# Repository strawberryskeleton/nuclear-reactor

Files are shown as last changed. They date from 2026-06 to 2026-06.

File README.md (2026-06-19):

# nuclear-reactor
ironman's arc reactor themed sound responsive pendant

## Inspiration from:
Link: [link to youtube video](https://www.youtube.com/watch?v=0NRY9WaExDg)

## Features
- has a ironman arc reactor top plate
- the case should be translucent enough for light to shine through
- has rechargeable battery
- programmable leds to react to sound picked up from mic
- has a notch to attach ribbon to make it a pendant

## Schematics
> microcontroller used is Xiao ESP32-S3 + charger module is not needed

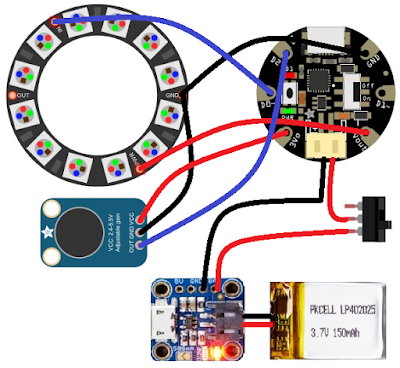
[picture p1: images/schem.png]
schem


## Case - 3D Printed

case assembled - top
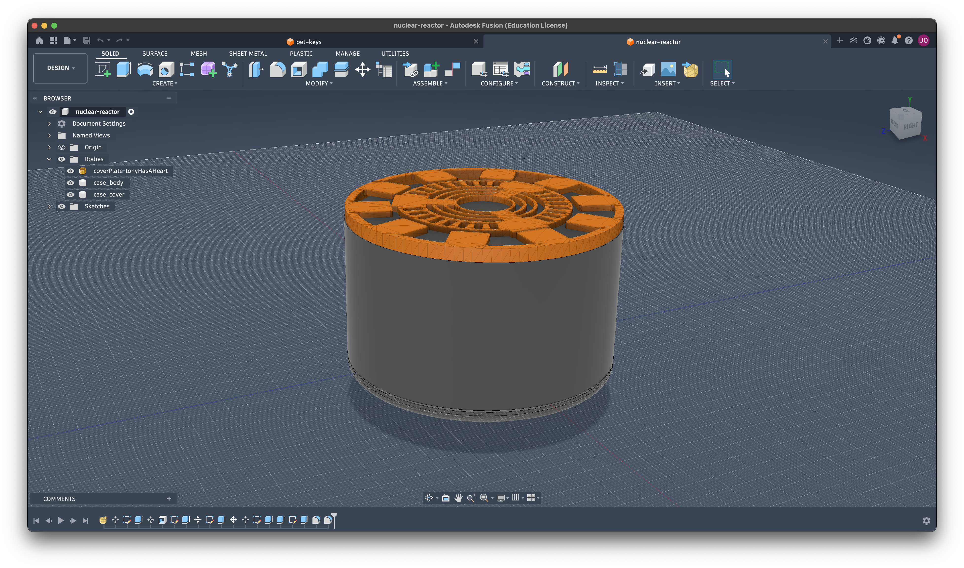
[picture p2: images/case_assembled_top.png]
case assembled - top


case assembled - bottom
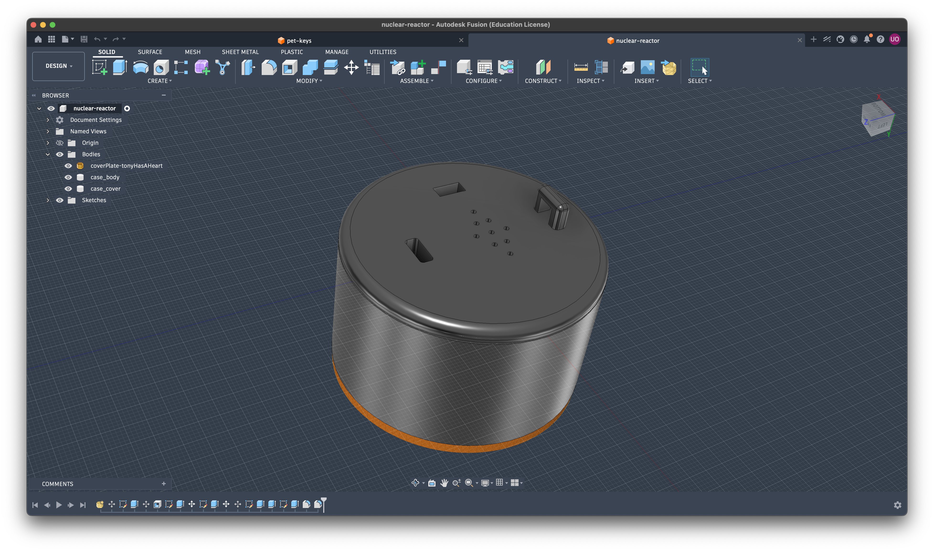
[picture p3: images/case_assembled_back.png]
case assembled - bottom


case lid
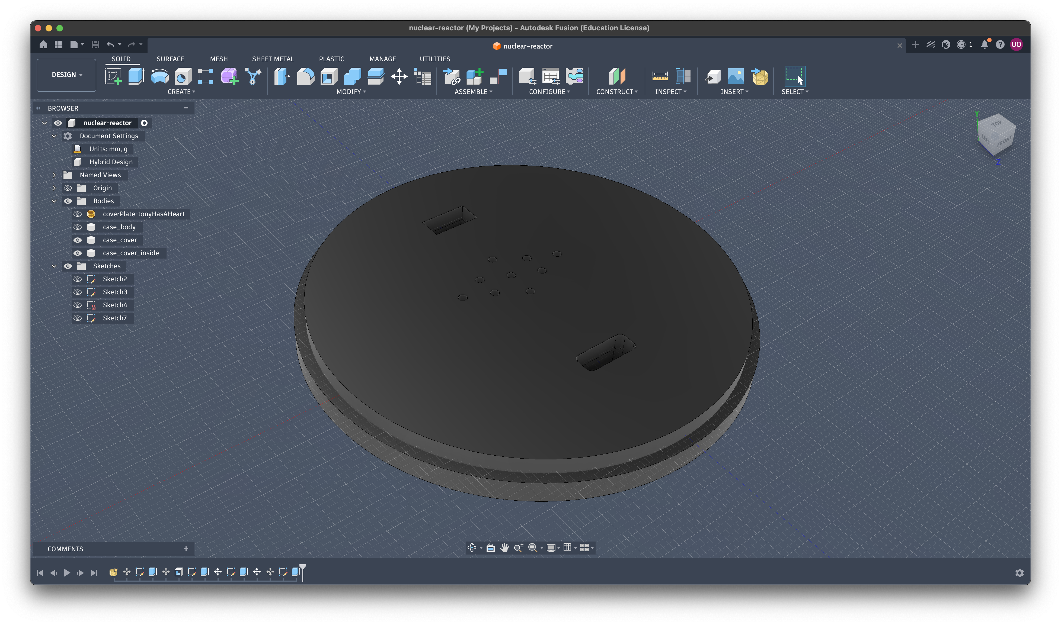
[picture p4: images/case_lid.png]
case lid


## BOM
| S. | Component | Quantity | Price (INR) | Price (USD) | Link |
|----|---|---|---|---|---|
| 1. | 3D Printed Case | 1 | (shipping only) | - | from printing-legion |
| 2. | Xiao ESP32-S3 | 1 | 1034.00 | 10.96 | https://robocraze.com/products/seeed-studio-xiao-esp32-s3-development-board-supports-wi-fi-bluetooth-5-0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 |
| 3. | Slide Switch SPDT | 1 | 9.00 | 0.095 | https://robocraze.com/products/slide-switch-3-pin-2-way-spdt?variant=44698610237664 |
| 4. | Rechargeable LiPo Battery | 1 | 102.00 | 1.08 | https://robocraze.com/products/witty-fox-160mah-rechargeable-3-7v-lipo-battery?variant=47479826481376 |
| 5. | WS2812 7-Bit Round LED Board | 1 | 89.00 | 0.94 | https://www.amazon.in/gp/product/B073DDRSLD/ref=ox_sc_act_title_1?smid=A31PUIOPHJ56Y3&psc=1 |
| 6. | MAX4466 Microphone Amplifier | 1 | 222.00 | 2.35 | https://www.amazon.in/gp/product/B0973CRZ25/ref=ox_sc_act_title_3?smid=A31PUIOPHJ56Y3&psc=1 |
| 7. | WS2812b LED Strip Lights | 1 | 249.00 | 2.64 | https://www.amazon.in/gp/product/B0CXVKBRM8/ref=ox_sc_act_title_2?smid=A5EYW98BF5M8Q&th=1 |

**Total Cost**: 1705.00 INR = 18.07 USD (excluding shipping needed by printing legion)

> Note #1: need something around $20-$22 to cover any conversion tax + shipping by printing legion

> Note #2: conversion rate might change. one in BOM is as per google on 19 Jun 1:25am IST

> NOTE #3: had to get 1m led strip since couldn't find any that was shorter

## Credits
- made by me
- 3D case made in Fusion
- Schem in KiCad
- case top design plate from: [https://www.printables.com/model/624553-wearable-arc-reactor/files]

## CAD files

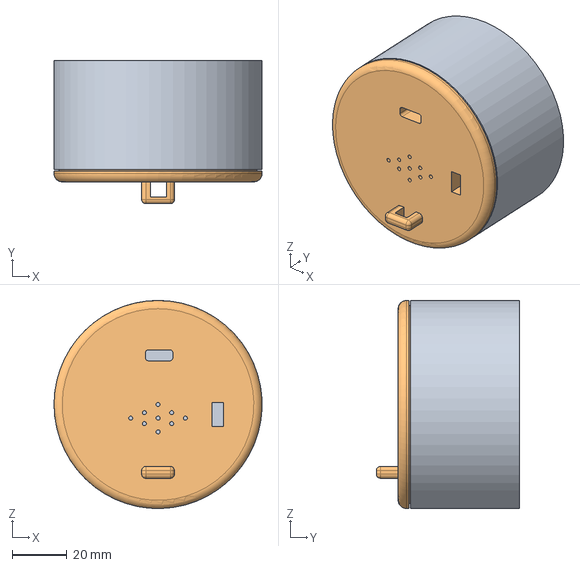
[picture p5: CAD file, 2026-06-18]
files/case_assembled.step
76.1 x 52.5 x 76.1 mm

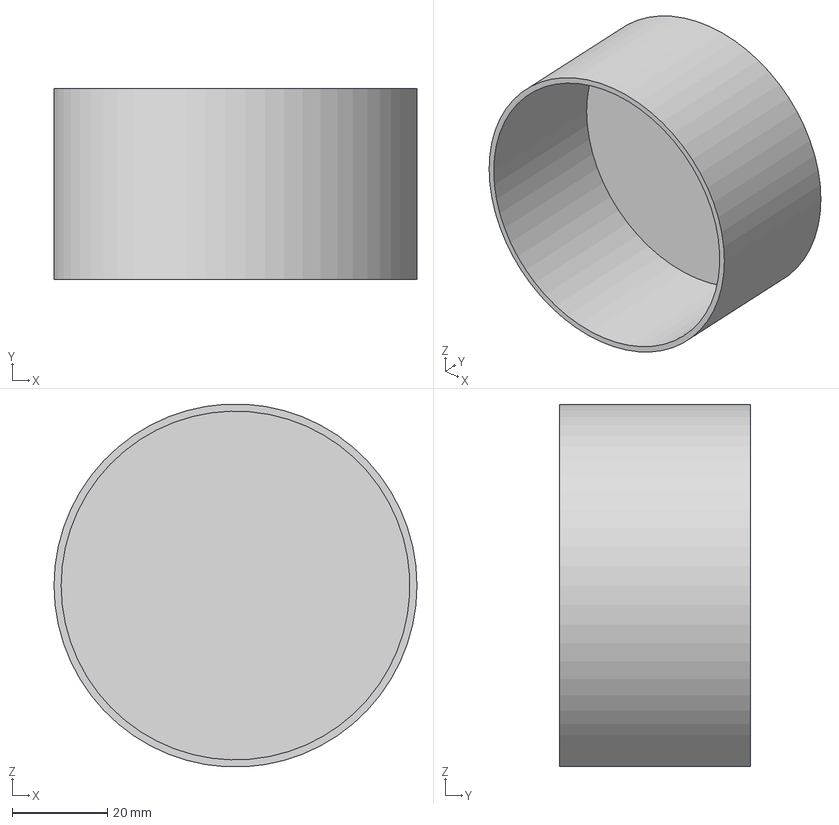
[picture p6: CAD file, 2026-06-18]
files/case_body.step
76.2 x 40.0 x 76.0 mm

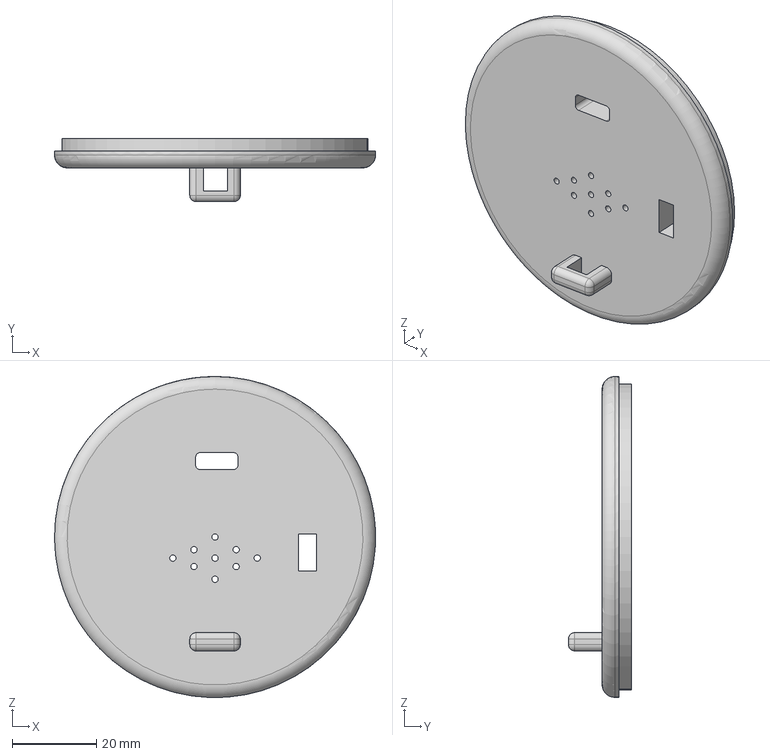
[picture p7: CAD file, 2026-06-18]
files/case_lid.step
76.1 x 15.0 x 76.1 mm

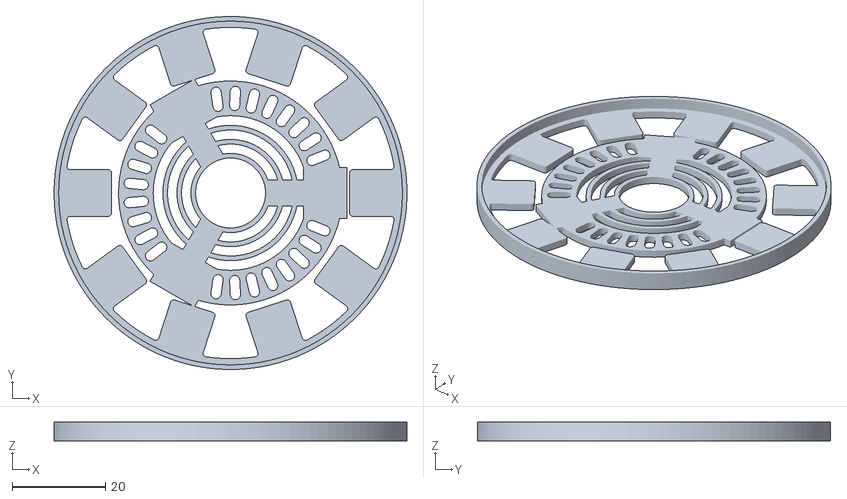
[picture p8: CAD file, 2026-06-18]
files/coverPlate-tonyHasAHeart.stl
75.6 x 75.6 x 4.00

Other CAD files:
files/base_lid.stl
files/case_assembled.stl
files/case_body.stl

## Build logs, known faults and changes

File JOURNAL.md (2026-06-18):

# JOURNAL
---
**Date: 18 Jun, 1:00am**

**Time Spent: 1hr 15min**

**What I Did:**

1. researched about the project like electronics needed, case, what other people have already made, etc.

2. made a few rough designs

rough design page #1
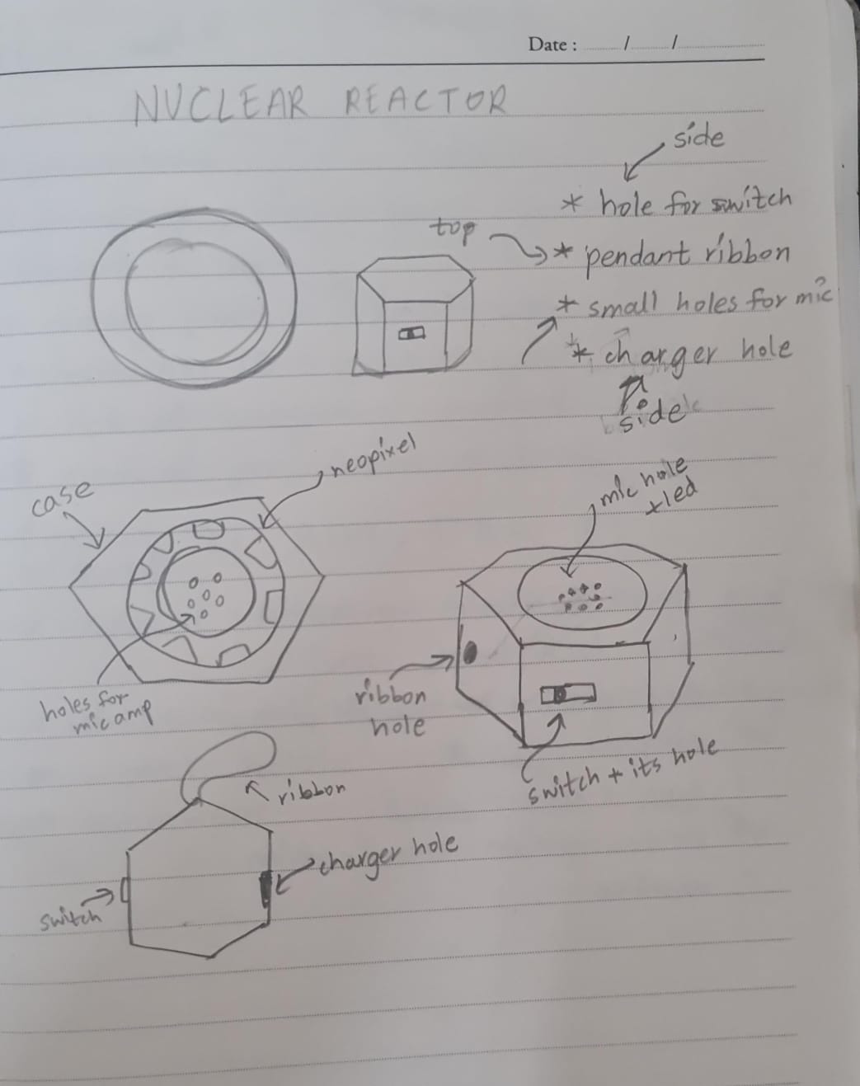
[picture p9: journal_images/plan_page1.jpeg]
rough design page #1


rough design page #2
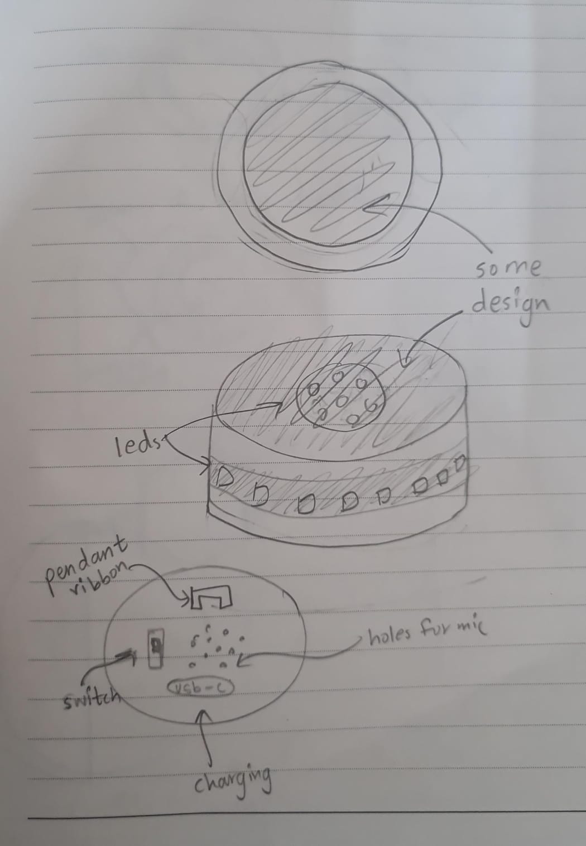
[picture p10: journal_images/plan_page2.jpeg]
rough design page #1


3. went to sleep

---

**Date: 18 Jun, 12:30pm**

**Time Spent: 2hr**

**What I Did:**

1. finalised the component + rough design

2. found out how to make the case so that it can act as a diffuser

3. found the top design plate : iron man arc reactor one

[link to plate](https://www.printables.com/model/624553-wearable-arc-reactor/files)

4. started with the case:
- added the plate wrong
- re-added the plate
- made the main shell for the case

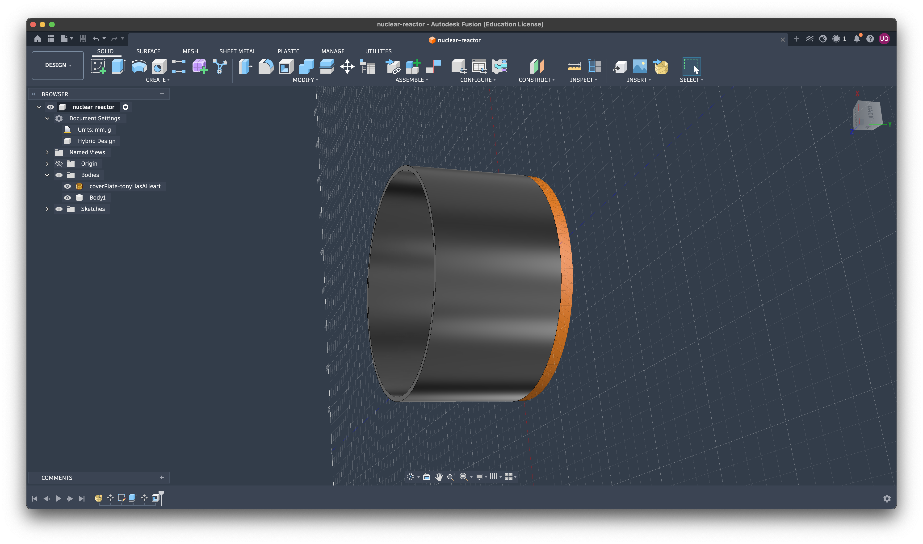
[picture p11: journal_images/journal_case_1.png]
case at this point


---

**Date: 18 Jun, 2:50pm**

**Time Spent: 1hr**

**What I Did:**

Made the back cover for the case

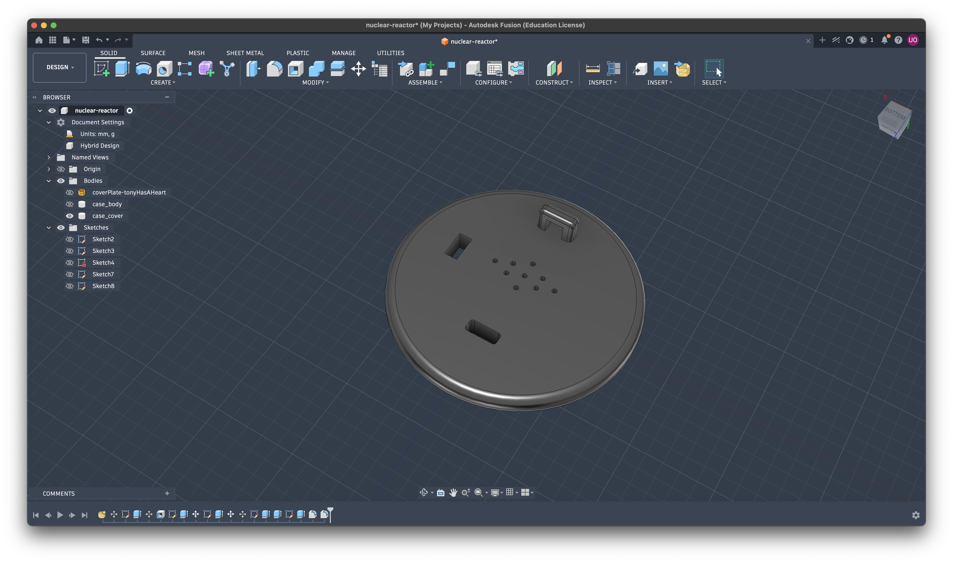
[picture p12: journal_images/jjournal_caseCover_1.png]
back cover


Steps I followed:
- made a list of all the holes I needed in the case
- found out the measurements for the components
- tried to add holes on the circular case side => could not fiugre it out
- decided to modify the design to include holes on the back cover only
- added hole for the slider spdt switch
- added hole for usb-c for charging module
- added tiny holes for the mic to catch the sound easily
- added a loop for the pendant ribbon

> note: the back cover of the case is attached usuing glue, and the components are also put in place using glue (i'm unable to can build housing fo reach component)

---

**Date: 19 Jun, 1:40am**

**Time Spent: 1hr**

**What I Did:**

made BOM
added images
wrote readme
completed journal
started with the schematics

---

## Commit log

2026-06-18 journal #1
    [coverPlate-tonyHasAHeart.stl]
2026-06-18 added BOM
    [bom.csv]
2026-06-18 added cad files
    [base_lid.stl, case_assembled.step, case_assembled.stl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]
2026-06-18 added images + readme
    [schem-nuclear-reactor.kicad_pcb, schem-nuclear-reactor.kicad_sch]
